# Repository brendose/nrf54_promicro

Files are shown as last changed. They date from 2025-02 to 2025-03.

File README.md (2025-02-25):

<h1 align="center">Welcome to Project: nrf54_promicro </br> (nRF54L1x Pro Micro inspired development board) </h1>
<div align="center">

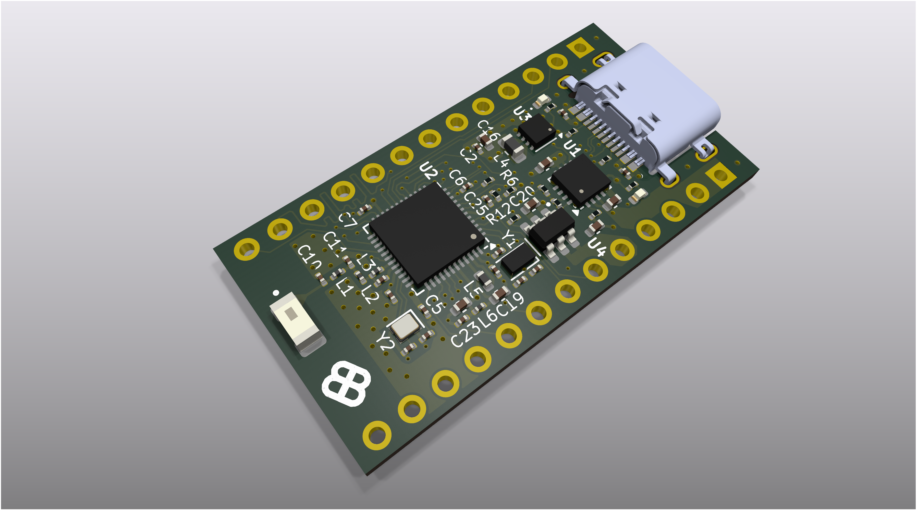
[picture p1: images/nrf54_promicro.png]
  
  
<a href="#introduction">Introduction</a> &nbsp;&bull;&nbsp;
<a href="#directory">Directory</a> &nbsp;&bull;&nbsp;
<a href="#documentation">Documentation</a> &nbsp;&bull;&nbsp;
<a href="#notes">Notes</a>
</div>

# Introduction
The <b>nrf54_promicro</b> project revolutionizes nRF52840 based keyboard projects by utilizing the Nordic Semiconductors nRF54L10/L15 Bluetooth transceiver, achieving sub-100uA/MHz power draw!
<br>
<br>
We're challenging the status quo of limited wireless keyboard battery life with the nRF54L15/L10, achieving unprecedented power efficiency. Why? Because Bluetooth based keyboard designs require decent battery life.
The nRF52840 power draw limits the battery life of most keyboard based projects, however, moving to the nRF54 the power draw can be minimized to a under 100uA/MHz. This Pro Micro-inspired board, designed in KiCad 9, 
integrates optimized power circuitry such as; the use of a high efficiency switching power supply, carefully selected low quiescent current (Iq) load switch and meticulous RF antenna tuning, wasting no power and
offering a development platform for keyboards that redefines what it means to have "good battery life".

The board contains:

- A Nordic Semiconductors nRF54L10 / nRF54L15 (ARM Cortex M33 and RISC-V coprocessor)
- 2.45GHz Chip Antenna supporting Bluetooth LE
- Texas Instruments BQ24075 battery charger
- 2x 13 pin GPIO headers 
- USB-C connector, with bit-banged USB interface
- Charge Status indicator LED
- Bluetooth Status indicator LED

### Projects top-level directory

    .
    ├── bom                      # Bill of Materials
    ├── images                   # Images used on this GitHub page
    ├── libs                     # Local component library
    ├── plots                    # Assembly drawings of the design
    ├── schematics               # Schematics of the design      
    └── README.md

## Documentation

TBD

## Notes

This repository is not actively maintained, so if you spot any bugs, please <a href="hhttps://github.com/brendose/nrf54_promicro/issues/new">raise an issue</a> and I will try get to it.

This is not an officially supported Google product.

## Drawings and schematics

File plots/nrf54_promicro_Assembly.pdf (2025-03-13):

### BOARD CHARACTERISTICS

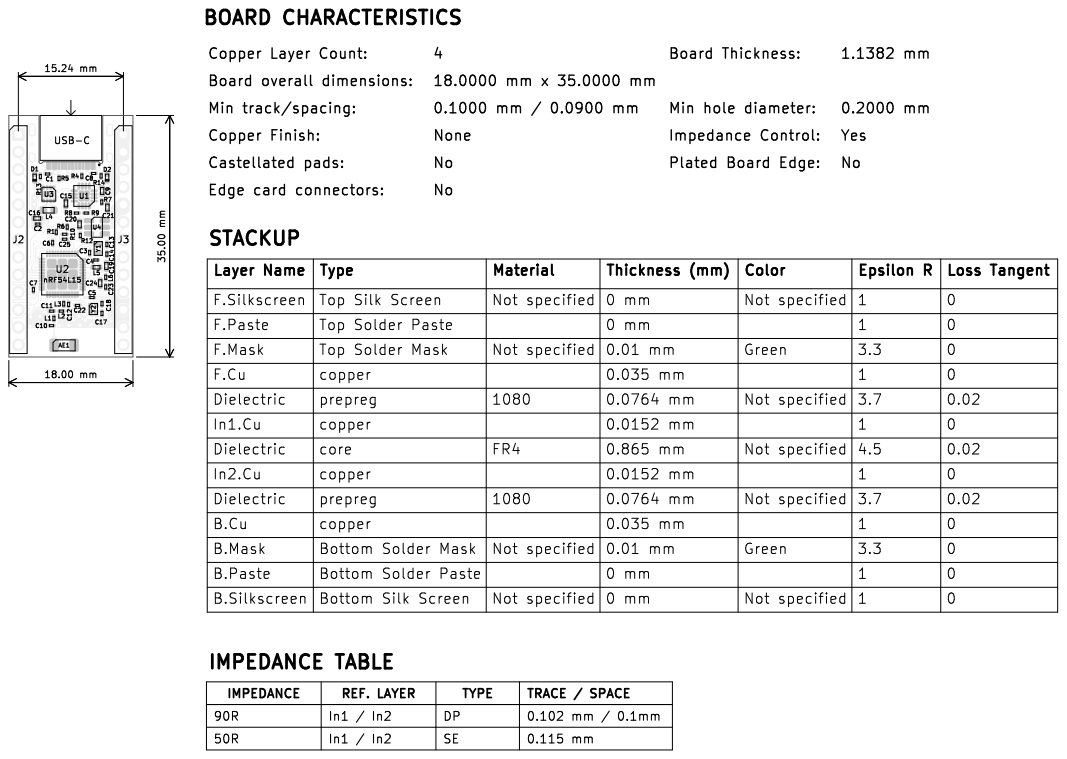
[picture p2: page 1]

Proto Bottom Silk Screen

F.Cu | FR4 | Plated Board Edge: | 3.3 Bottom Solder Paste Min track/spacing: 1Epsilon R | 0

Edge card connectors: | | Top Silk Screen | | | 0.01 mm 0 mm | | | 0 No
copper B.Mask | | 0 mm | | 1 No | 0 STACKUP 0

F.Mask | | | Not specified | 0.01 mm | | 1 Not specified

In1.Cu | | | | 0.0152 mm | | | 0 Not specified

prepreg | | | 0.0764 mm | | 3.7 | 0.02

0.865 mm | | 4.5 | 0 Dielectric

0.0764 mm | | | 3.7 | 0.02 Not specified 0.02

Green | 3.3

0 mm
0 mm | | | 1

IMPEDANCE | REF. LAYER | TYPE | TRACE / SPACE
90R | In1 / In2 | DP | 0.102 mm / 0.1mm
50R | In1 / In2 | SE | 0.115 mm

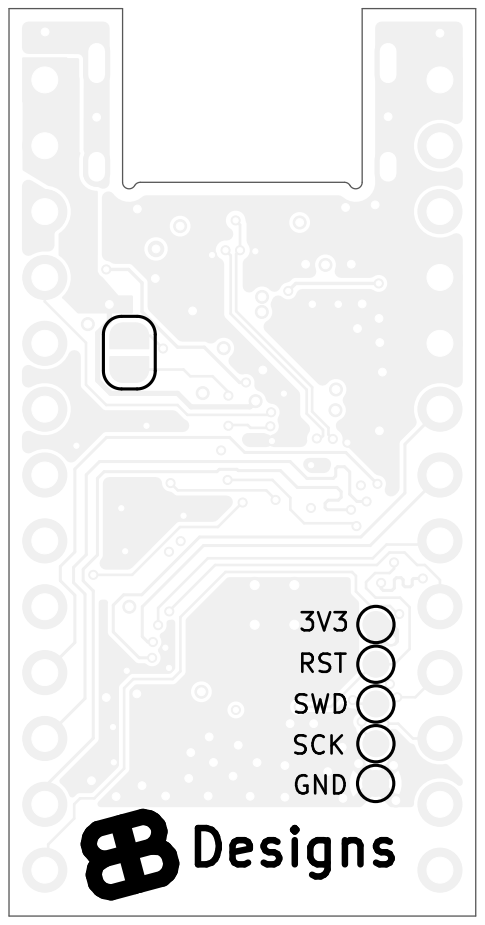
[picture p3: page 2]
3V3 SCK Designs RST GND B SWD; D Date: 2025-03-12 KiCad; E.D.A. 9.0.0 Size: A4; Rev:; Proto; File: nrf54_promicro.kicad_pcb Sheet: Black; And; White; BOT BB; Designs

Id: /1 Title: nRF54 ProMicro

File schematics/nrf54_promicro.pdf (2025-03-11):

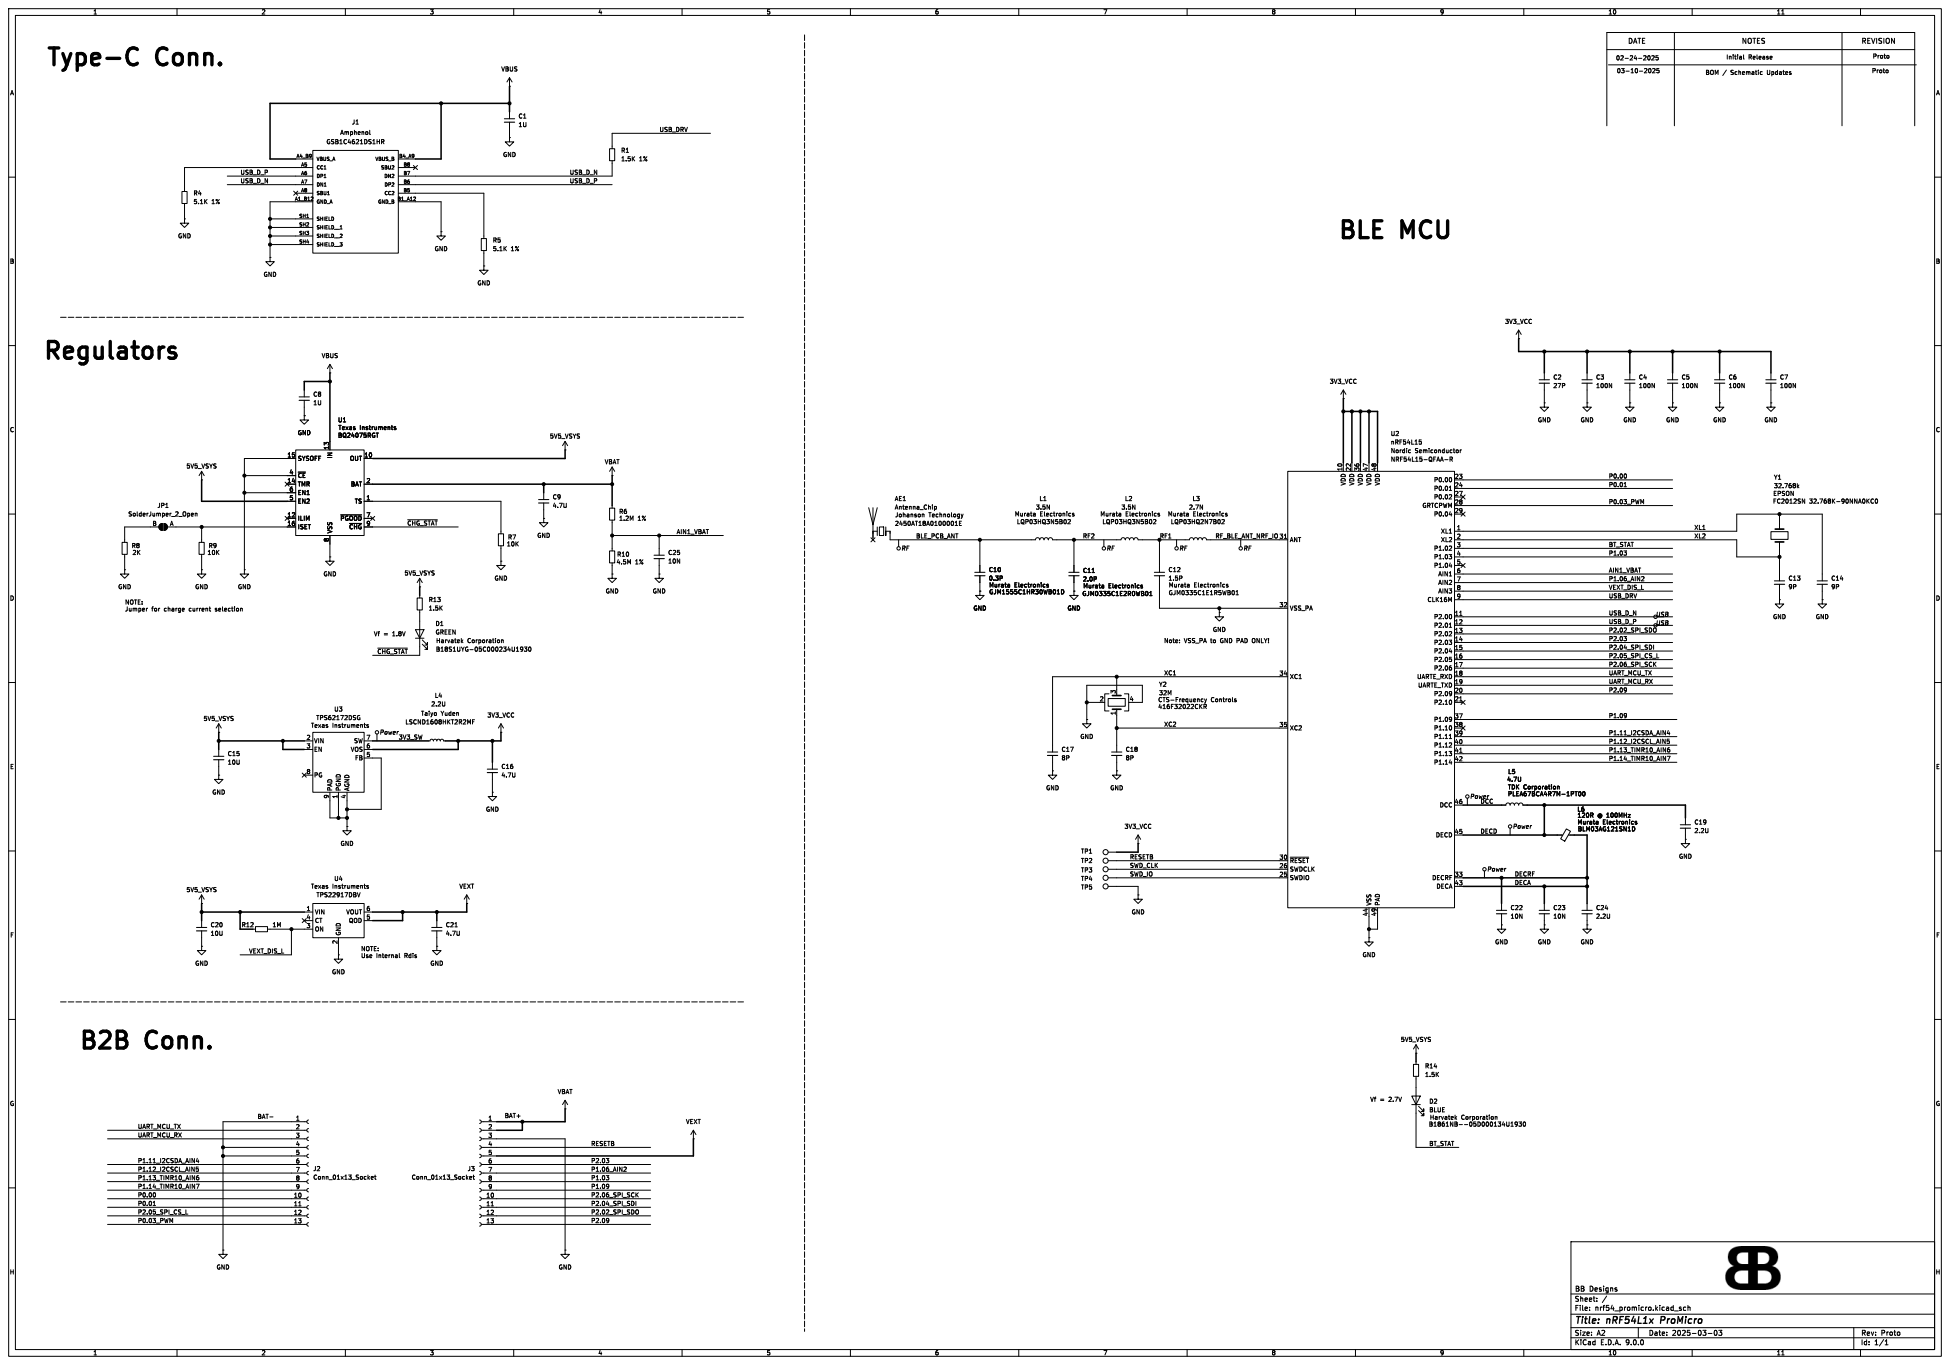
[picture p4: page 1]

Texas Instruments SYSOFF 15 ~{CE} 4 TMR 14 EN1 6 EN2 5

8 OUT 10 BAT 2 TS 1 ~{PGOOD}7 ~{CHG}9 U1BQ24075RGT
Texas Instruments

8 OUT 10 BAT 2 TS 1 ~{PGOOD}7 ~{CHG}9 GND
SYSOFF 15 ~{CE} 4 TMR 14 EN1 6 EN2 5

NOTE: Jumper for charge current selection

Note: VSS_PA to GND PAD ONLY!

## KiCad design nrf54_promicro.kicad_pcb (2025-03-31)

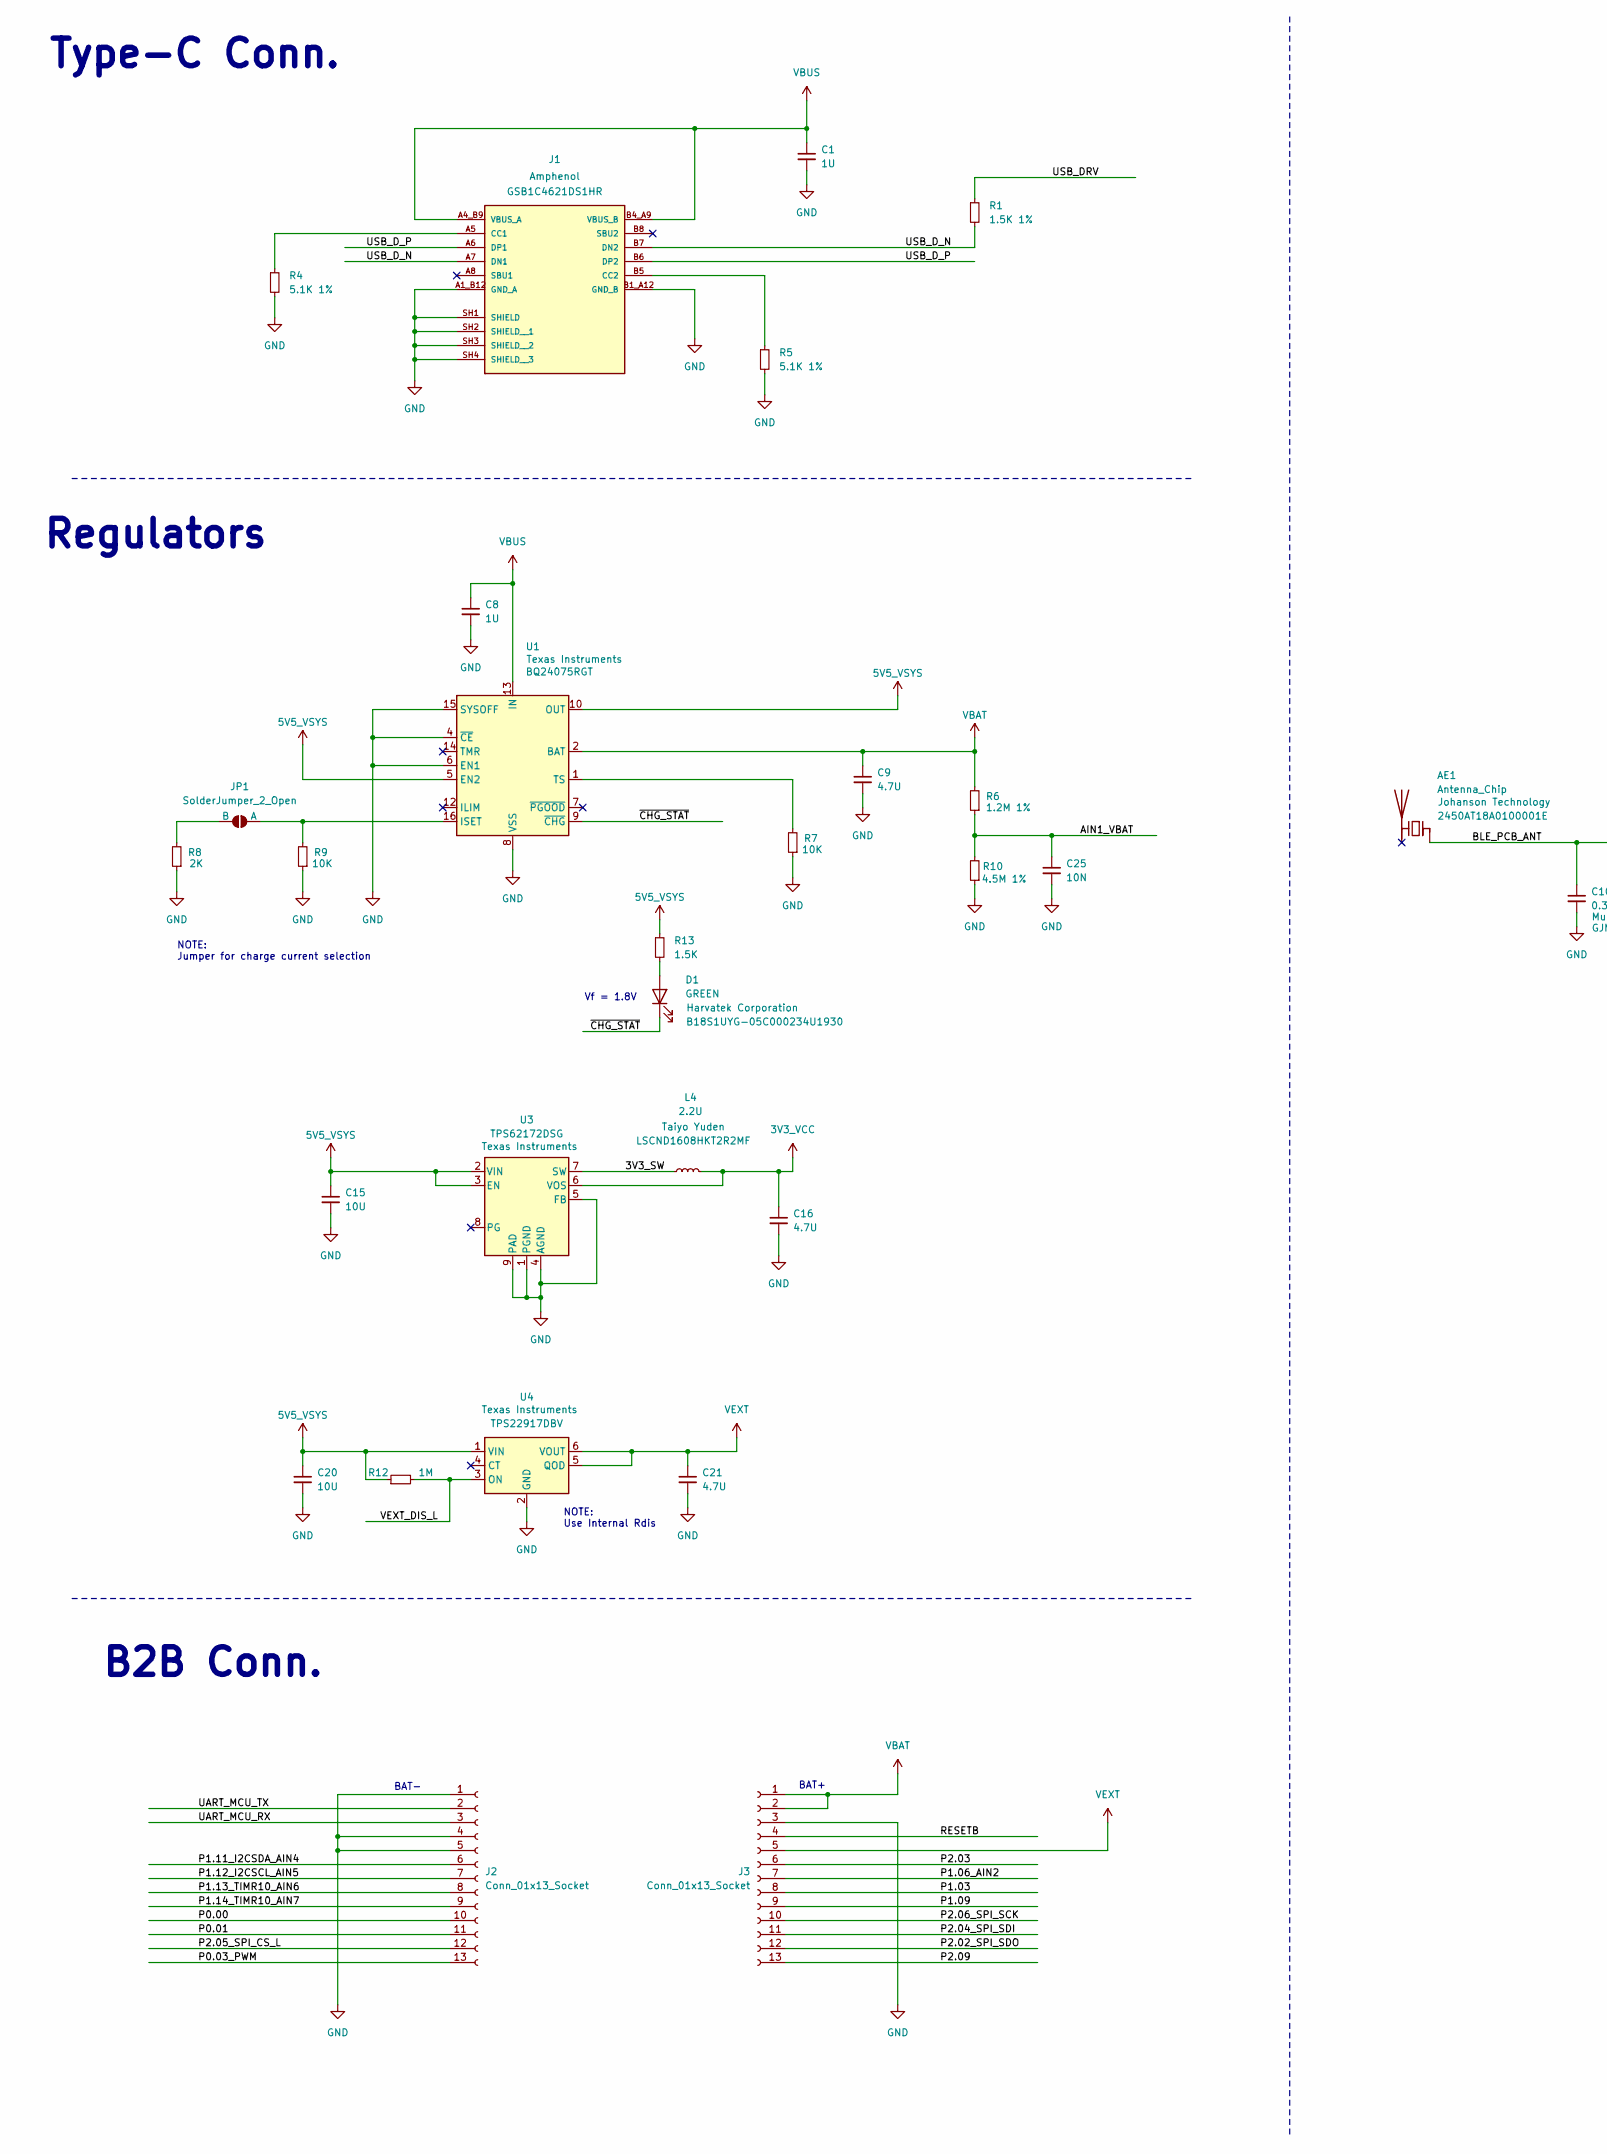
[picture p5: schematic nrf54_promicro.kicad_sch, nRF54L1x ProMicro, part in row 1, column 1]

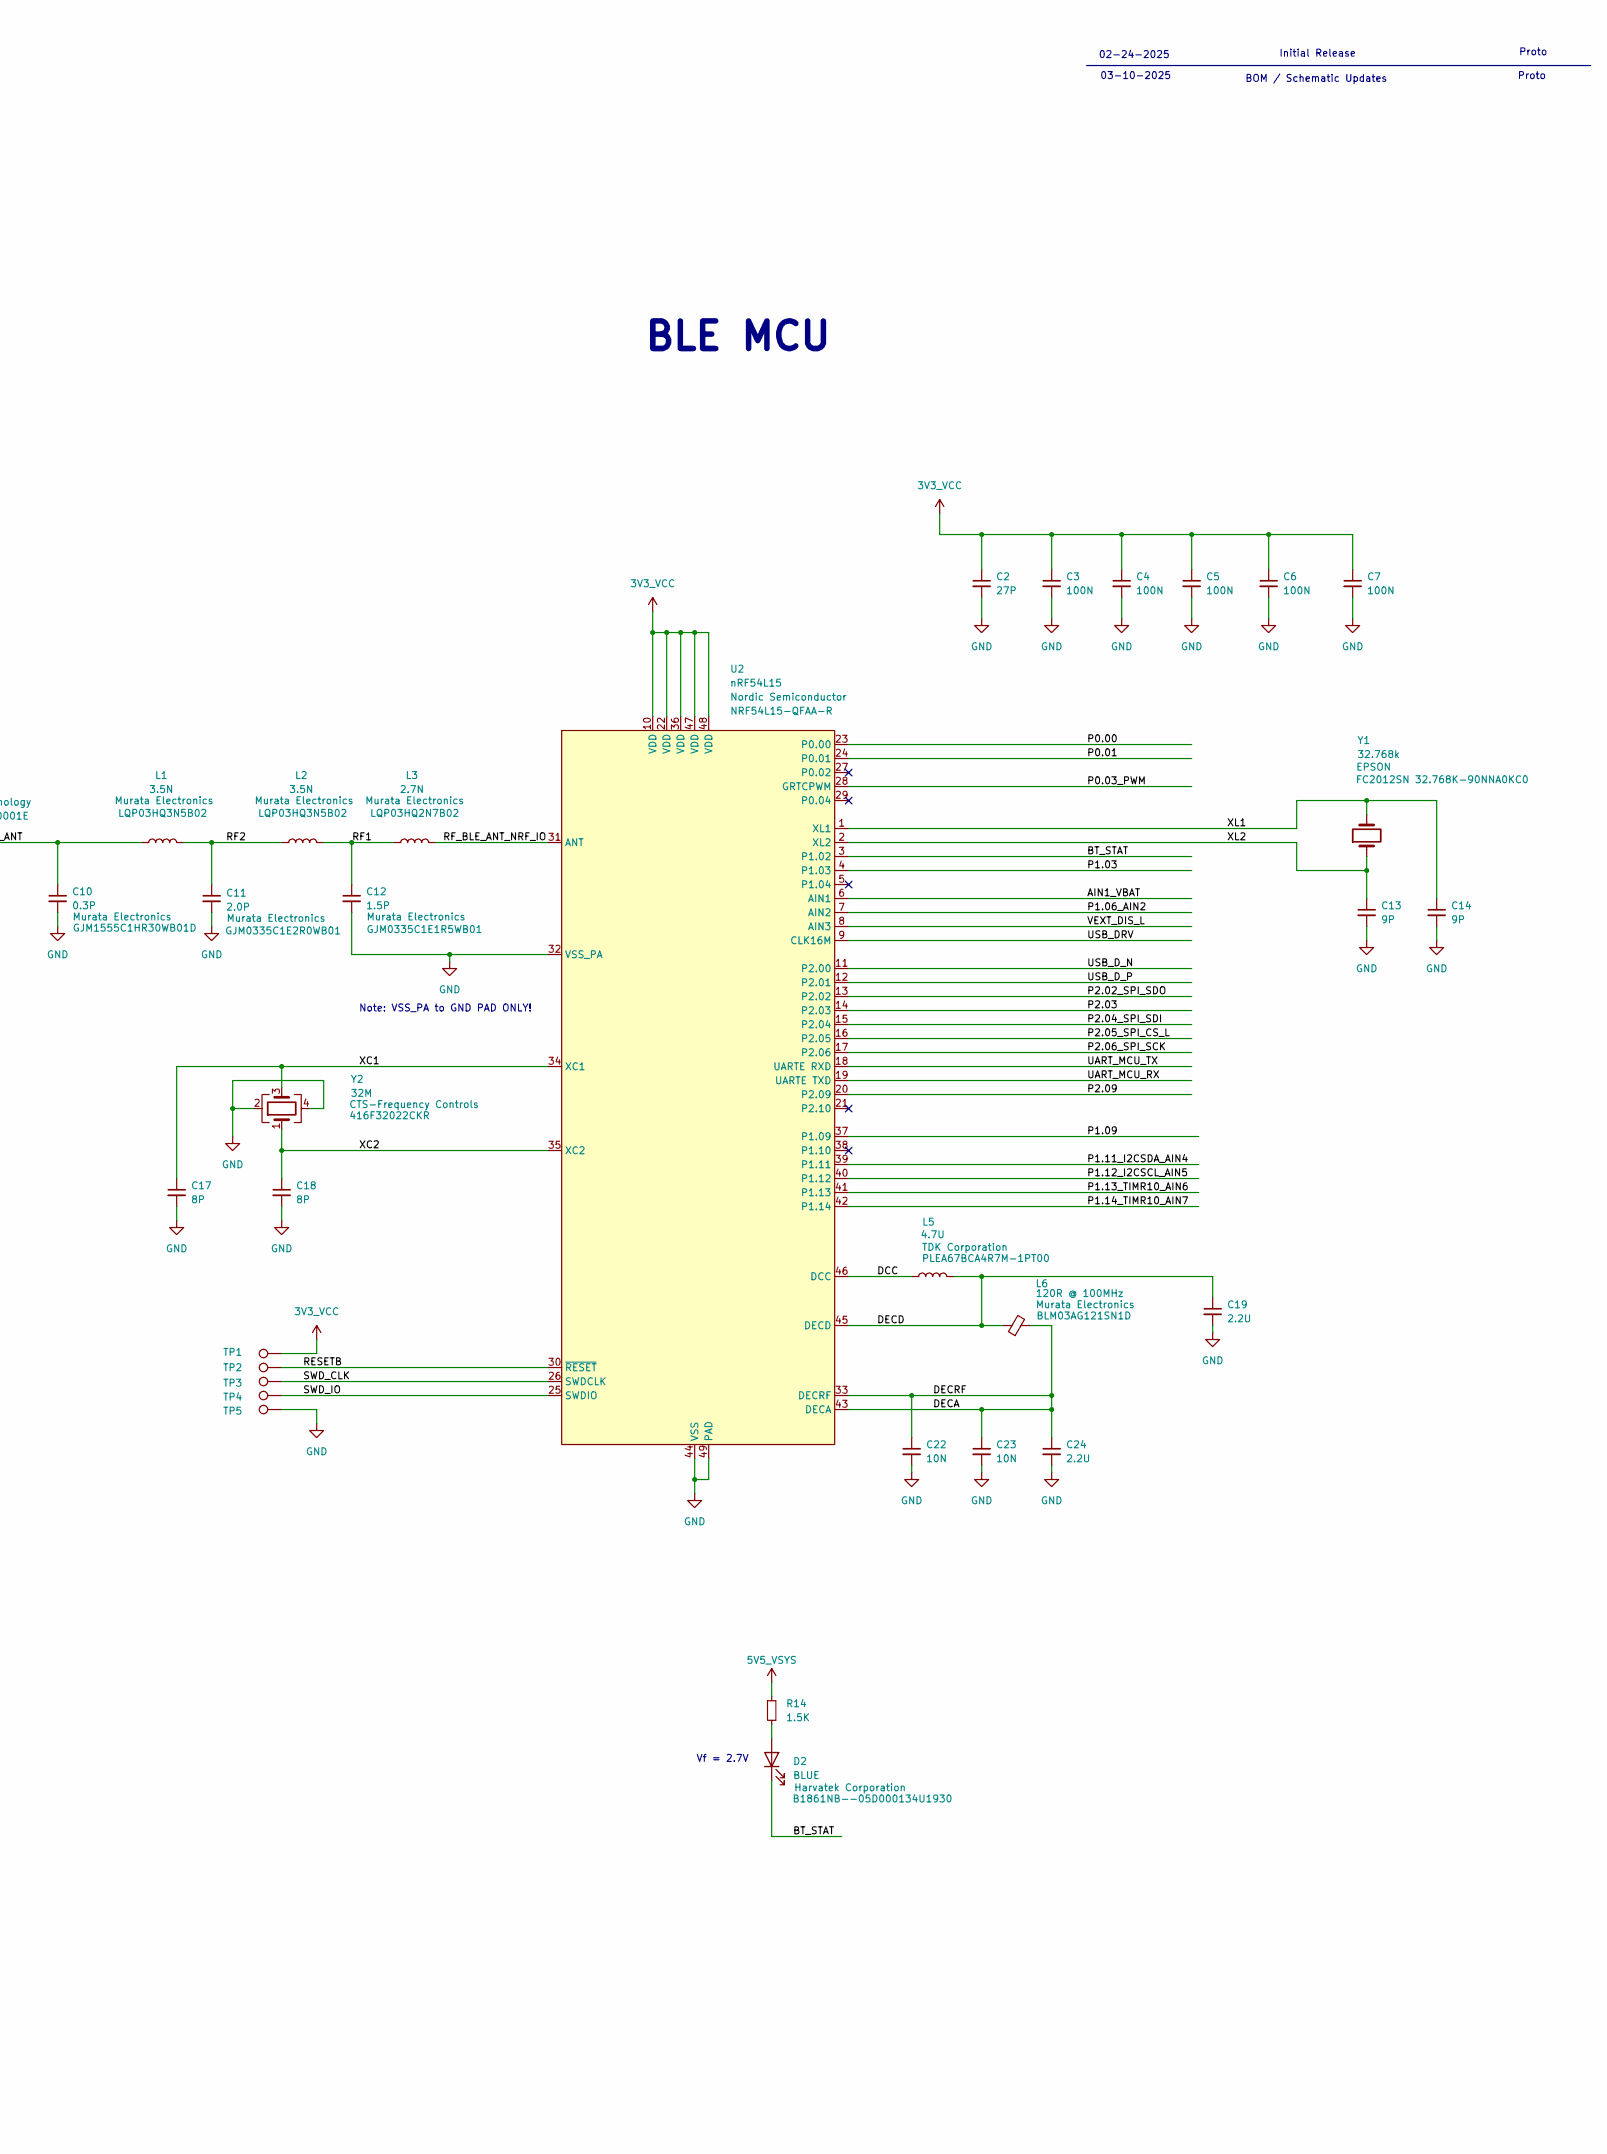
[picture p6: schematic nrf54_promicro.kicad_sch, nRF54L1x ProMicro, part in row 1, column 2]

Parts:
AE1: Antenna_Chip; Johanson_2450AT18x100; MFG_PN 2450AT18A0100001E
C1, C8: 1U; C_0201_0603Metric
C2: 27P; C_0201_0603Metric
C3, C4, C5, C6, C7: 100N; C_0201_0603Metric
C9, C16, C21: 4.7U; C_0402_1005Metric
C10: 0.3P; C_0201_0603Metric; MFG_PN GJM1555C1HR30WB01D
C11: 2.0P; C_0201_0603Metric; MFG_PN GJM0335C1E2R0WB01
C12: 1.5P; C_0201_0603Metric; MFG_PN GJM0335C1E1R5WB01
C13, C14: 9P; C_0201_0603Metric
C15, C20: 10U; C_0402_1005Metric
C17, C18: 8P; C_0201_0603Metric
C19, C24: 2.2U; C_0402_1005Metric
C22, C23, C25: 10N; C_0201_0603Metric
D1: GREEN; LED_0402_1005Metric; MFG_PN B18S1UYG-05C000234U1930
D2: BLUE; LED_0402_1005Metric; MFG_PN B1861NB--05D000134U1930
J1: GSB1C4621DS1HR; AMPHENOL_GSB1C4621DS1HR; PARTREV AX1
J2, J3: Conn_01x13_Socket; PinHeader_1x13_P2.54mm_Vertical
JP1: SolderJumper_2_Open; SolderJumper-2_P1.3mm_Open_RoundedPad1.0x1.5mm
L1, L2: 3.5N; L_0201_0603Metric; MFG_PN LQP03HQ3N5B02
L3: 2.7N; L_0201_0603Metric; MFG_PN LQP03HQ2N7B02
L4: 2.2U; L_0603_1608Metric; MFG_PN LSCND1608HKT2R2MF
L5: 4.7U; L_0402_1005Metric; MFG_PN PLEA67BCA4R7M-1PT00
L6: 120R @ 100MHz; L_0201_0603Metric; MFG_PN BLM03AG121SN1D
R1: 1.5K 1%; R_0201_0603Metric
R4, R5: 5.1K 1%; R_0201_0603Metric
R6: 1.2M 1%; R_0201_0603Metric
R7, R9: 10K; R_0201_0603Metric
R8: 2K; R_0201_0603Metric
R10: 4.5M 1%; R_0201_0603Metric
R12: 1M; R_0201_0603Metric
R13, R14: 1.5K; R_0201_0603Metric
TP1, TP2, TP3, TP4, TP5: TestPoint; TestPoint_Pad_D1.0mm
U1: BQ24075RGT; VQFN-16-1EP_3x3mm_P0.5mm_EP1.6x1.6mm; MFG_PN BQ24075RGTR
U2: nRF54L15; QFN-48-1EP_6x6mm_P0.4mm_EP4.6x4.6mm; MFG_PN NRF54L15-QFAA-R
U3: TPS62172DSG; WSON-8-1EP_2x2mm_P0.5mm_EP0.9x1.6mm_ThermalVias; MFG_PN TPS62172DSGT
U4: TPS22917DBV; SOT-23-6; MFG_PN TPS22917DBVR
Y1: 32.768k; Crystal_SMD_2012-2Pin_2.0x1.2mm; MFG_PN FC2012SN 32.768K-90NNA0KC0
Y2: 32M; Oscillator_SMD_Abracon_ASCO-4Pin_1.6x1.2mm; MFG_PN 416F32022CKR

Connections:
3V3_VCC: C2.1, C3.1, C4.1, C5.1, C6.1, C7.1, C16.1, L4.2, TP1.1, U2.10 (VDD), U2.22 (VDD), U2.36 (VDD), U2.47 (VDD), U2.48 (VDD), U3.6 (VOS)
5V5_VSYS: C15.1, C20.1, R12.1, R13.1, R14.1, U1.5 (EN2), U1.10 (OUT), U1.11 (OUT), U3.2 (VIN), U3.3 (EN), U4.1 (VIN)
/3V3_SW: L4.1, U3.7 (SW)
/AIN1_VBAT: C25.1, R6.1, R10.2, U2.6 (AIN1)
/BLE_PCB_ANT: AE1.1 (FEED), C10.1, L1.1
/BT_STAT: D2.1 (K), U2.3 (P1.02)
/DCC: L5.1, U2.46 (DCC)
/DECA: C22.1, C23.1, C24.1, L6.2, U2.33 (DECRF), U2.43 (DECA)
/DECD: C19.1, L5.2, L6.1, U2.45 (DECD)
/P0.00: J2.10, U2.23 (P0.00)
/P0.01: J2.11, U2.24 (P0.01)
/P0.03_PWM: J2.13, U2.28 (GRTCPWM)
/P1.03: J3.8, U2.4 (P1.03)
/P1.06_AIN2: J3.7, U2.7 (AIN2)
/P1.09: J3.9, U2.37 (P1.09)
/P1.11_I2CSDA_AIN4: J2.6, U2.39 (P1.11)
/P1.12_I2CSCL_AIN5: J2.7, U2.40 (P1.12)
/P1.13_TIMR10_AIN6: J2.8, U2.41 (P1.13)
/P1.14_TIMR10_AIN7: J2.9, U2.42 (P1.14)
/P2.02_SPI_SDO: J3.12, U2.13 (P2.02)
/P2.03: J3.6, U2.14 (P2.03)
/P2.04_SPI_SDI: J3.11, U2.15 (P2.04)
/P2.05_SPI_CS_L: J2.12, U2.16 (P2.05)
/P2.06_SPI_SCK: J3.10, U2.17 (P2.06)
/P2.09: J3.13, U2.20 (P2.09)
/RESETB: J3.4, TP2.1, U2.30 (~RESET)
/RF1: C12.1, L2.2, L3.1
/RF2: C11.1, L1.2, L2.1
/RF_BLE_ANT_NRF_IO: L3.2, U2.31 (ANT)
/SWD_CLK: TP3.1, U2.26 (SWDCLK)
/SWD_IO: TP4.1, U2.25 (SWDIO)
/UART_MCU_RX: J2.3, U2.19 (UARTE TXD)
/UART_MCU_TX: J2.2, U2.18 (UARTE RXD)
/USB_DRV: R1.1, U2.9 (CLK16M)
/USB_D_N: J1.A7 (DN1), J1.B7 (DN2), R1.2, U2.11 (P2.00)
/USB_D_P: J1.A6 (DP1), J1.B6 (DP2), U2.12 (P2.01)
/VEXT_DIS_L: R12.2, U2.8 (AIN3), U4.3 (ON)
/XC1: C17.1, U2.34 (XC1), Y2.3
/XC2: C18.1, U2.35 (XC2), Y2.1
/XL1: C14.1, U2.1 (XL1), Y1.2
/XL2: C13.1, U2.2 (XL2), Y1.1
/~CHG_STAT: D1.1 (K), U1.9 (~CHG)
GND: C1.2, C2.2, C3.2, C4.2, C5.2, C6.2, C7.2, C8.2, C9.2, C10.2, C11.2, C12.2, C13.2, C14.2, C15.2, C16.2, C17.2, C18.2, C19.2, C20.2, C21.2, C22.2, C23.2, C24.2, C25.2, J1.A1_B12 (GND_A), J1.B1_A12 (GND_B), J1.SH1 (SHIELD), J1.SH2 (SHIELD__1), J1.SH3 (SHIELD__2), J1.SH4 (SHIELD__3), J2.1, J2.4, J2.5, J3.3, R4.2, R5.2, R7.1, R8.1, R9.1, R10.1, TP5.1, U1.4 (~CE), U1.6 (EN1), U1.8 (VSS), U1.15 (SYSOFF), U1.17 (VSS), U2.32 (VSS_PA), U2.44 (VSS), U2.49 (PAD), U3.1 (PGND), U3.4 (AGND), U3.5 (FB), U3.9 (PAD), U4.2 (GND), Y2.2, Y2.4
unnamed: D1.2 (A), R13.2
unnamed: D2.2 (A), R14.2
unnamed: J1.A5 (CC1), R4.1
unnamed: J1.B5 (CC2), R5.1
unnamed: JP1.1 (A), R9.2, U1.16 (ISET)
unnamed: JP1.2 (B), R8.2
unnamed: R7.2, U1.1 (TS)
VBAT: C9.1, J3.1, J3.2, R6.2, U1.2 (BAT), U1.3 (BAT)
VBUS: C1.1, C8.1, J1.A4_B9 (VBUS_A), J1.B4_A9 (VBUS_B), U1.13 (IN)
VEXT: C21.1, J3.5, U4.5 (QOD), U4.6 (VOUT)

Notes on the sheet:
Proto
NOTE: Jumper for charge current selection
03-10-2025
Note: VSS_PA to GND PAD ONLY!
BAT+
BOM / Schematic Updates
02-24-2025
Initial Release
BLE MCU
Type-C Conn.
NOTE: Use Internal Rdis
Vf = 2.7V
BAT-
Regulators
B2B Conn.
Vf = 1.8V

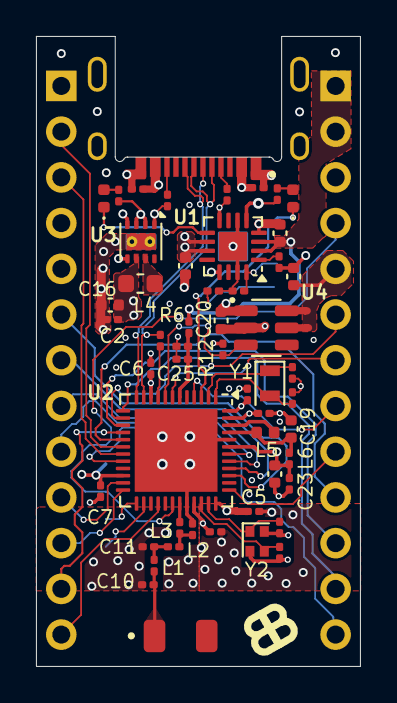
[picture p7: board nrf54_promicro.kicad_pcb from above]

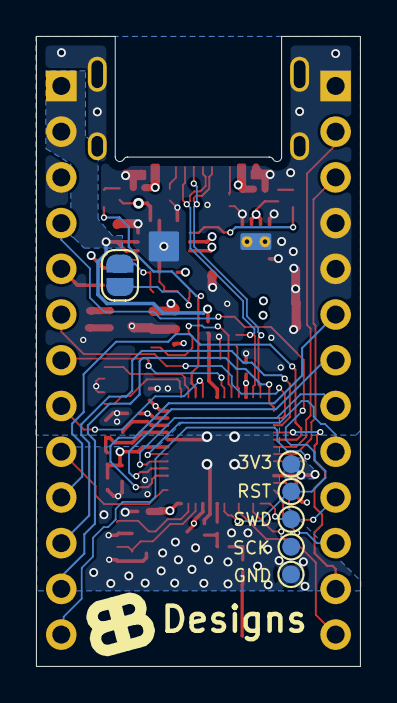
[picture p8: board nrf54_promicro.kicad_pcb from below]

Board: 4 copper layers, 18.0 x 35.0 mm, 60 parts (6 on the bottom side), 53 nets.

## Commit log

2025-02-24 Continued to improve layout. Updated README.md
    [nrf54_promicro.kicad_pcb, nrf54_promicro.kicad_sch]
2025-02-24 Improved Layout. Improved Silk/Fab.
    [nrf54_promicro.kicad_pcb]
2025-02-25 Swapped U4 for lower Iq load switch. Fixed DRCs. Fixed Layout.
    [nrf54_promicro.kicad_pcb, nrf54_promicro.kicad_sch]
2025-02-25 Updated REAMDME.md. Moved lib files. Generated some output documentation.
    [nrf54_promicro.kicad_pcb, nrf54_promicro.kicad_sch]
2025-03-02 BOM updates, schematic and layout updated due to BOM updated
    [nrf54_promicro.kicad_pcb, nrf54_promicro.kicad_sch]
2025-03-02 Assembly and SS layer updates, Image update.
    [nrf54_promicro.kicad_pcb]
2025-03-06 BOM Updates. Layout Updates.
    [nrf54_promicro.kicad_pcb, nrf54_promicro.kicad_sch]
2025-03-11 Moved USB_D_P/N to MCU Domain for increased bus BW. Improved RF layout. Improved PI. Changed IO for improved MCU escape.
    [nrf54_promicro.kicad_pcb, nrf54_promicro.kicad_sch]
2025-03-13 Fixed Assembly Layers.
    [nrf54_promicro.kicad_pcb]
2025-03-31 Modified layout - remove SPI LM. Removed GND shape around pins.
    [nrf54_promicro.kicad_pcb]
